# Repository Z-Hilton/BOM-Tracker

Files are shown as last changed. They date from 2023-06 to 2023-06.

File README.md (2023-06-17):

# BOM-Tracker
A guide to how I built the ultimate DIY Book of Mormon Progress Tracker. It is designed to help with reading goals and make tracking your progress through the Book of Mormon just a bit more fun.

## Background
I wanted something that would essentially function like a glorified bookmark, keeping track of stats, times, progress, averages, etc. I thought about making an app for a smartphone, but decided that another app that I eventually forget about wouldn't be as exciting as a physical piece of hardware that can sit on my nightstand as a constant reminder that I only get to click its buttons if I have read :) (Also, I try to avoid being on my phone before going to bed). Thus the idea to use a microcontroller was born. I thought abut using a Teensy 3.2 since I already have one, but decided that for reproducability's sake I would use the much cheaper $4 Raspberry Pi Pico. 

## Functionality
* *Time tracking:* You can start, pause and stop a timer to track your time spent reading. The spent time will be displayed briefly on the OLED screen before returning to the normal UI, then after 7 times, it will calculate your weekly average and display that to the screen, allowing you to see if you met your goal. 
* *Chapter progress tracking:* You can increment and decrement which chapter you're on and update the display accordingly. Then it will do the math to show the total progress and display it on the OLED screen as a percentage or progress bar.
* *User interface:* It has a simple UI consisting of a few buttons for selecting chapters and start/pause/stopping the timer. The OLED display will provide feedback on the device's status and progress. An external LED shows the current timer status (started = on, paused = blinking, stopped = off). 

## Bill of Materials
Warning: *the following cost analysis assumes you have access to an FDM and Resin 3D printer. These are based on rates I found locally at BYU* 

I spent about $25 on this project, and ended up with lots of extra parts. I also had to iterte a few times on my designs for the housing and the keycaps before they worked well. In theory you could build this in under $17.30:
Item # | Description | Quantity | Cost Per Item | Cost
---|---|---|---|---
1 | [Raspberry Pi Pico](https://www.raspberrypi.com/products/raspberry-pi-pico/) | 1 | $4.00 | $4.00
2 | [Micro USB Cable](https://www.amazon.com/CableWholesale-10-Feet-Micro-Cable-10U2-03110BK/dp/B002I8MUJG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) | 1 | $2.00 | $2.00
3 | [PLA filament](https://www.amazon.com/OVERTURE-Filament-Consumables-Dimensional-Accuracy/dp/B07PGY2JP1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) | 50 grams | $20/kg | $1.00
4 | LED (any color) | 1 | $0.10 | $0.10
5 | [Keyboard Switches](https://www.amazon.com/Switches-Replaceable-Equivalent-Keyswitch-Mechanical/dp/B09WHDJJBT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) | 3 | $10/10pc | $3.00
6 | Resin Keycaps | 3 | $0.25/ml | $1.20
7 | [SSH1106 1.3" OLED](https://www.amazon.com/Teyleten-Robot-Display-Raspberry-Microcontroller/dp/B08J1D212N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) | 1 | $12/2pc | $6.00

## Build/Pictures
[Here is a link](https://www.thingiverse.com/thing:4816077) to the model I started with and modified to suit the needs of my 3 buttons and OLED screen. They are relatively simple edits and can be done very quickly in Fusion 360. I did not modify the bottom half, and the changes I made to the top half are reflected in the .stp file I exported and included above. 

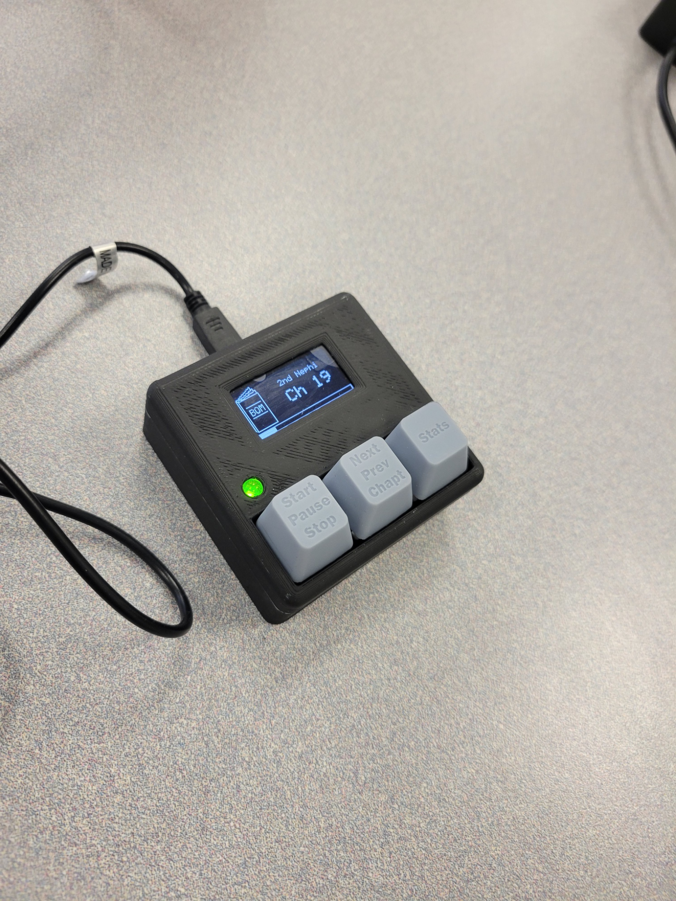
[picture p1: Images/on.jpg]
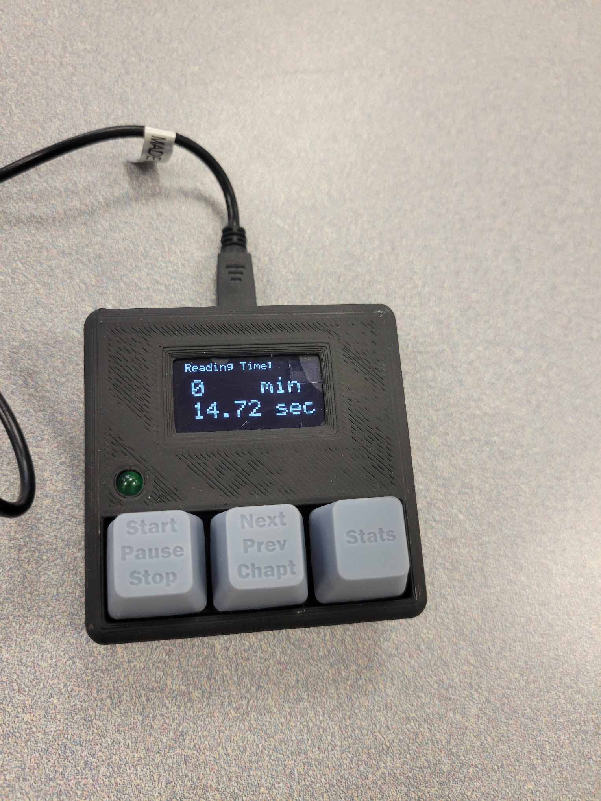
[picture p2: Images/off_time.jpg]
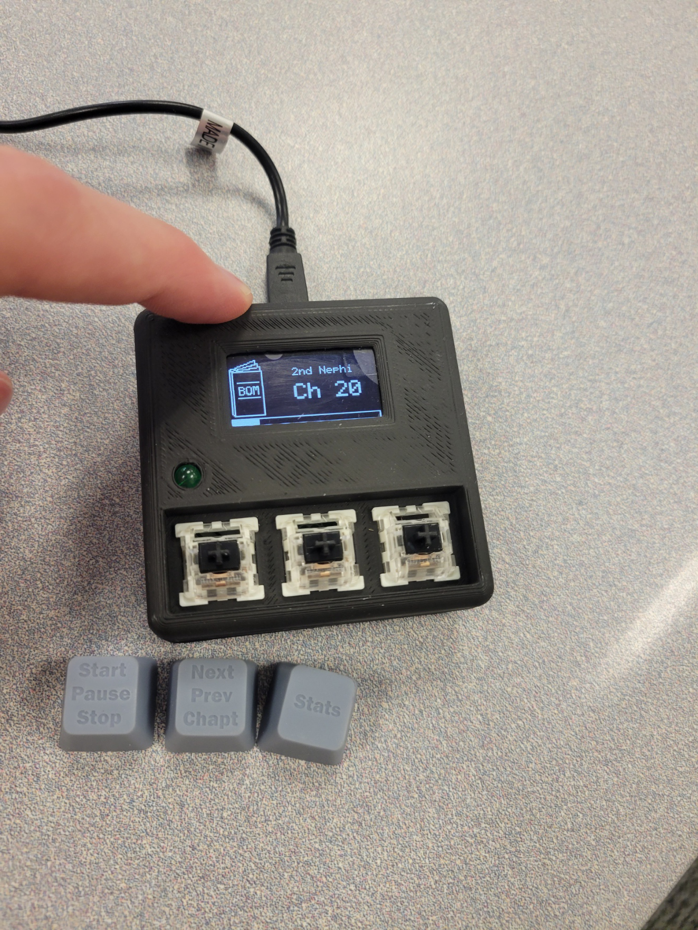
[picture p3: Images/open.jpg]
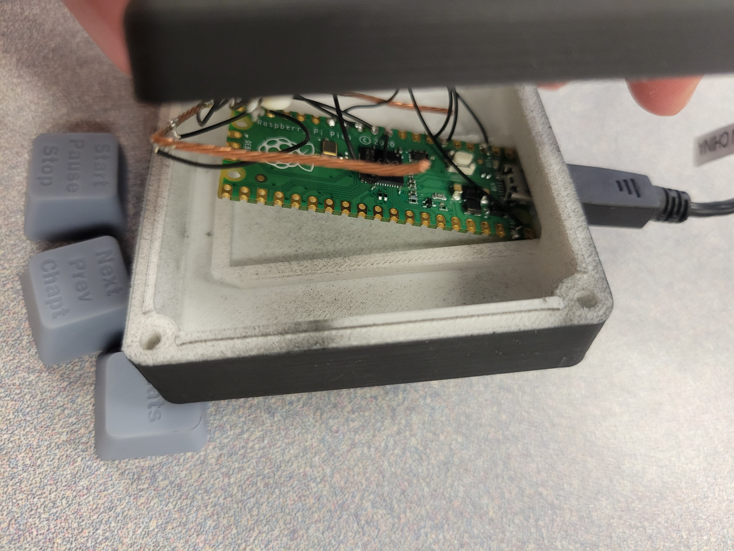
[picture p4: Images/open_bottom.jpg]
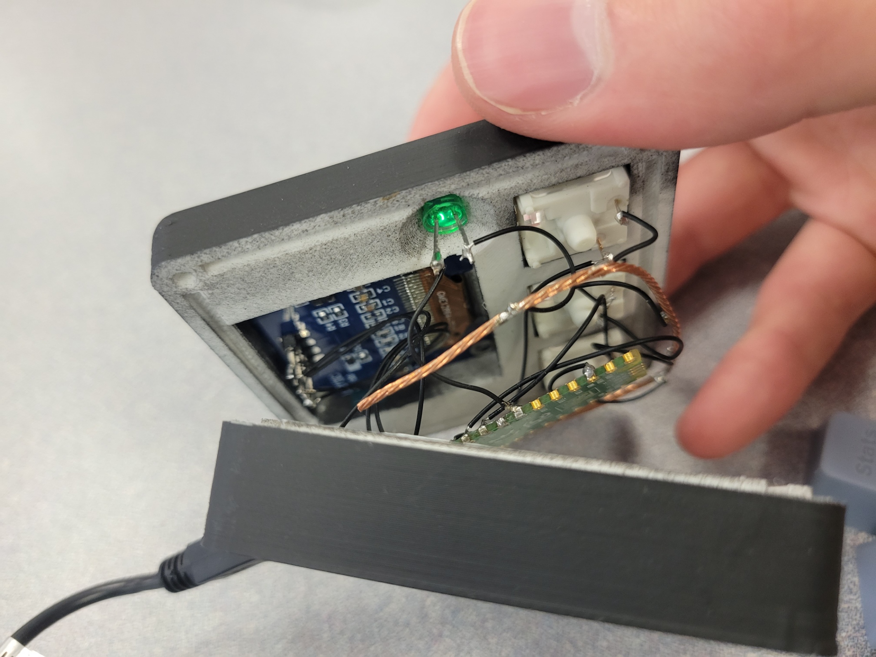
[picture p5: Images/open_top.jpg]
    

## Video


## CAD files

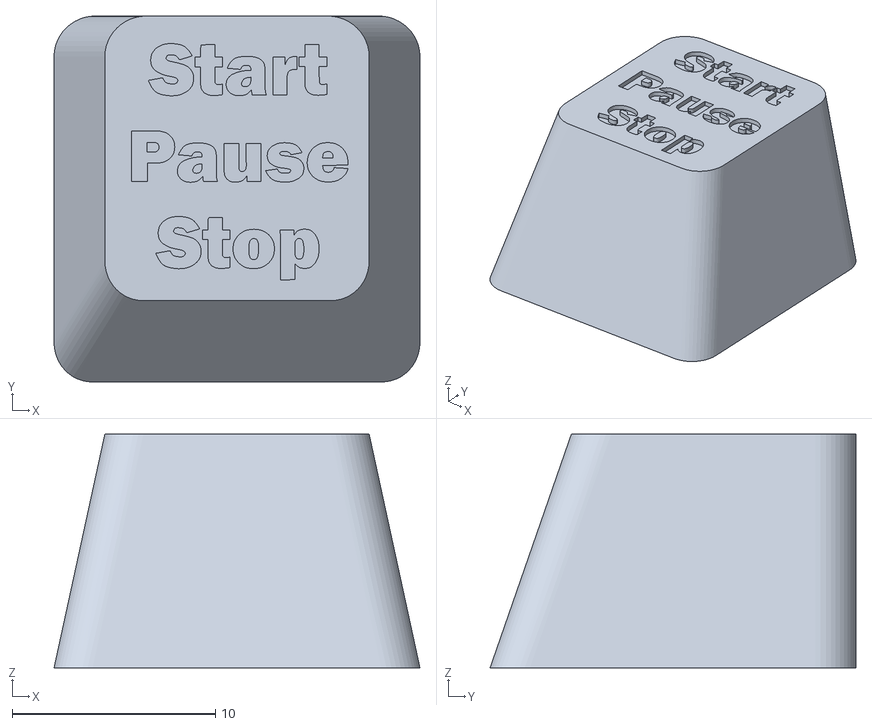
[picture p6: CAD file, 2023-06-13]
cherry_mx_key_cap_edited.stl
18.0 x 18.0 x 11.5

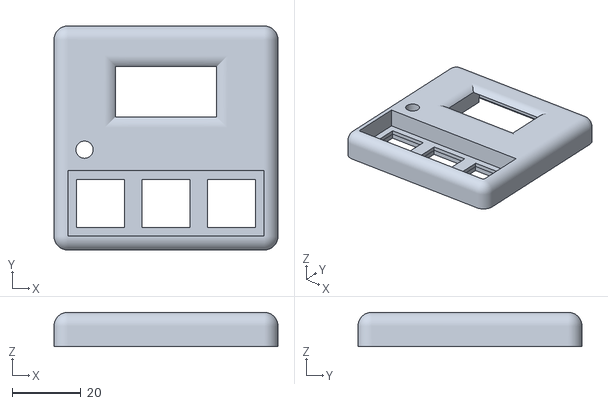
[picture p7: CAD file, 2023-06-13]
case_top.stl
65.2 x 65.1 x 10.0

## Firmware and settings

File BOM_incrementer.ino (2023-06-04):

#define SPLASH_SCREEN_FRAME_COUNT 1
#define SPLASH_SCREEN_WIDTH 32
#define SPLASH_SCREEN_HEIGHT 63

const unsigned char splashScreen [] PROGMEM = {
0x00, 0x80, 0x80, 0x80, 0x80, 0xC0, 0x40, 0xA0, 0xA0, 0xA0, 0x90, 0x90, 0x50, 0x48, 0x48, 0x28,
0x24, 0xA4, 0xA2, 0xB2, 0x92, 0x91, 0x9F, 0x88, 0x78, 0x40, 0xC0, 0x00, 0x00, 0x00, 0x00, 0x00,
0xFF, 0x03, 0xFE, 0x06, 0x05, 0x05, 0x07, 0x07, 0x06, 0x06, 0x06, 0x06, 0x05, 0x05, 0x05, 0x05,
0x05, 0x05, 0x04, 0x04, 0x04, 0x04, 0x04, 0x04, 0x04, 0x04, 0x07, 0xFC, 0x00, 0x00, 0x00, 0x00,
0xFF, 0x00, 0xFF, 0x00, 0x00, 0x00, 0x10, 0x10, 0x10, 0x10, 0x10, 0x10, 0x10, 0x10, 0x10, 0x10,
0x10, 0x10, 0x10, 0x10, 0x10, 0x10, 0x10, 0x10, 0x10, 0x00, 0x00, 0xFF, 0x00, 0x00, 0x00, 0x00,
0xFF, 0x00, 0xFF, 0x00, 0x00, 0x00, 0x00, 0xFF, 0x89, 0x89, 0x89, 0x76, 0x00, 0x7E, 0xC1, 0x81,
0xC1, 0x7E, 0x00, 0xFF, 0x03, 0x0E, 0x03, 0xFF, 0x00, 0x00, 0x00, 0xFF, 0x00, 0x00, 0x00, 0x00,
0xFF, 0x00, 0xFF, 0x00, 0x00, 0x00, 0x04, 0x04, 0x04, 0x04, 0x04, 0x04, 0x04, 0x04, 0x04, 0x04,
0x04, 0x04, 0x04, 0x04, 0x04, 0x04, 0x04, 0x04, 0x04, 0x00, 0x00, 0xFF, 0x00, 0x00, 0x00, 0x00,
0xFF, 0x00, 0xFF, 0x00, 0x00, 0x00, 0x00, 0x00, 0x00, 0x00, 0x00, 0x00, 0x00, 0x00, 0x00, 0x00,
0x00, 0x00, 0x00, 0x00, 0x00, 0x00, 0x00, 0x00, 0x00, 0x00, 0x00, 0xFF, 0x00, 0x00, 0x00, 0x00,
0x01, 0x02, 0x07, 0x04, 0x04, 0x04, 0x04, 0x04, 0x04, 0x04, 0x04, 0x04, 0x04, 0x04, 0x04, 0x04,
0x04, 0x04, 0x04, 0x04, 0x04, 0x04, 0x04, 0x04, 0x04, 0x04, 0x04, 0x07, 0x00, 0x00, 0x00, 0x00,
0x00, 0x00, 0x00, 0x00, 0x00, 0x00, 0x00, 0x00, 0x00, 0x00, 0x00, 0x00, 0x00, 0x00, 0x00, 0x00,
0x00, 0x00, 0x00, 0x00, 0x00, 0x00, 0x00, 0x00, 0x00, 0x00, 0x00, 0x00, 
};




#include <Bounce2.h>
#include <string.h>
#include <GyverOLED.h>

#define TOTAL_CHAPTERS 239.0
#define SCREEN_WIDTH 128
#define SCREEN_HEIGHT 64
#define HOLD_TIME 1000
#define SHOW_PROGRESS 0
#define SHOW_TIMES 1
#define SHOW_STATS 2
//Initialize LCD by creating an OLED  object
GyverOLED<SSH1106_128x64> oled;


//define buttons and LED
const int incrementDecrementButtonPin = 8;
const int startPauseStopButtonPin = 7; // will be startPauseStopPin
const int statButtonPin = 9; // will be stat pin
const int ledPin = 10;
Bounce incrementDecrementButton = Bounce();
Bounce startPauseStopButton = Bounce();
Bounce statButton = Bounce();

//Book of Mormon constants and variables
const int numBooks = 15; // number of Books in th Book of Mormon
const int numChapters[] = {0, 22, 33, 7, 1, 1, 1, 1, 29, 63, 16, 30, 1, 9, 15, 10};
int currentBook = 1;    // the current book (starts with 1st Nephi)
int currentChapter = 1; // the current chapter (it starts with 1)
double portion = 0; // the percentage of the way through the Book of Mormon you are
double avg = 0;
// Define inc/dec timer variables
int holdCnt = 0;
bool incDecPressed = false;

//Define Timer State variables
bool timerRunning = false;
bool timerPaused = false;
bool flashLedFlag = false;  // Flag to trigger flashing mechanism
bool on = true;             // Flag to remember the current state of the LED
double startTime = 0.0;
double pauseTime = 0.0;
double elapsedTime = 0.0;
double weeklyTimes[] = {0.0, 0.0, 0.0, 0.0, 0.0, 0.0, 0.0};
int timesIndex = 0;
int flashCnt = 0;
int mode = 0;

void setup() {
  // Set the pin modes
  pinMode(incrementDecrementButtonPin, INPUT_PULLUP);
  pinMode(startPauseStopButtonPin, INPUT_PULLUP);
  pinMode(statButtonPin, INPUT_PULLUP);
  pinMode(ledPin, OUTPUT);
  // start the serial communication
  Serial.begin(9600); 
  // attach the Bounce objects to the button pins and set debounce intervals
  incrementDecrementButton.attach(incrementDecrementButtonPin); 
  incrementDecrementButton.interval(20); 
  startPauseStopButton.attach(startPauseStopButtonPin);
  startPauseStopButton.interval(20);
  statButton.attach(statButtonPin);
  statButton.interval(20);
  //Initialize the OLED display
  oled.init();
  oled.clear();
  oled.update();
  printUI();
  printChapter();
  // oled.setCursorXY(28,26);
  // oled.print("Hello World!");
  // oled.rect(0,0,127,63,OLED_STROKE);
  // oled.update();
}

void loop() {
  incrementDecrementButton.update(); // update the bounce object for the inc. button
  startPauseStopButton.update();// etc.
  statButton.update();

  if (incrementDecrementButton.read() == LOW && incrementDecrementButton.duration() >= HOLD_TIME) {
    if (currentChapter == 1) { // if we are at the first chapter of any given book,
      currentBook = ((currentBook - 2 + numBooks) % numBooks) + 1; //move to the previous book (this line was hard)
      currentChapter = numChapters[currentBook]; //start at the last chapter 
    } else {
      currentChapter--; //decrement the current chapter
    }
    printChapter();
  }
  else if (incrementDecrementButton.fell()) {// if the increment button was pressed
    if (currentChapter == numChapters[currentBook]) {// if we are on the last chapter of a given book,
      currentBook = (currentBook % numBooks) + 1; // move on to the next book
      currentChapter = 1; // start at the first chapter of the book
    } else {
      currentChapter++; // increment the current chapter
    }
    printChapter();
  }

  //state machine for the timer

  // Check if stop button is pressed
  if (startPauseStopButton.read() == LOW && startPauseStopButton.duration() >= HOLD_TIME && timerRunning) {
    // Stop timer
    timerRunning = false;
    timerPaused = false;
    flashLedFlag = false;
    digitalWrite(ledPin, LOW);
    Serial.print("Elapsed time: ");

    printTime(elapsedTime/1000.0,2,false,false);
    pushElapsedTime();
    //delay(3000);
    //printChapter();
    
    elapsedTime = 0.0;
  }
  // Check if the start/pause button is pressed
  else if (startPauseStopButton.fell()) {
    if (!timerRunning) {
      // Start the timer
      timerRunning = true;
      startTime = millis();
      digitalWrite(ledPin, HIGH);
    } else if (timerPaused) {
      // Resume the timer
      timerPaused = false;
      flashLedFlag = false;
      startTime += millis() - pauseTime;
      digitalWrite(ledPin, HIGH);
    } else {
      // Pause Timer
      timerPaused = true;
      pauseTime = millis();
      flashLedFlag = true;
    }
  }

  //Update the elapsed time if timer is running
  if (timerRunning && !timerPaused) {
    elapsedTime = millis() - startTime;
  }
  // Flash the LED
  if (flashLedFlag) {
    flashCnt++;
    if (flashCnt >= 10000) {
      if(on) {
        digitalWrite(ledPin, LOW);
        on = false;
        flashCnt = 0;
      } else {
        digitalWrite(ledPin, HIGH);
        on = true;
        flashCnt = 0;
      }
    }
  }

  if (statButton.fell()) {
    switch (mode) {
      case SHOW_PROGRESS:
        printStats(); // if we are in progress mode, pressing the stat button will show us stats
      break;
      case SHOW_TIMES:
        printChapter(); // if we are in showTimes mode, pressing the stat button will go to the chapter progress
      break;
      case SHOW_STATS:
        printChapter(); // if we are in showStats mode, pressing the stat button will go back to chapter progress 
      break;
    }
  }

  //delay(10); //small delay to prevent bouncing
}
void printChapter() {
  mode = SHOW_PROGRESS;
  Serial.print("Ch ");
  Serial.print(currentChapter);
  Serial.print(" of ");
  Serial.println(bookName(currentBook));

  //clean slate with my BOM UI
  oled.clear();
  printUI();

  // chapter to oled
  oled.setScale(1);
  //We gotta fit Words of Mormon in there so here is the exception case
  if(currentBook == 7) {
    oled.setCursorXY(37, 10);
    oled.println(bookName(currentBook));
  } else {
    oled.setCursorXY(55, 10);
    oled.println(bookName(currentBook));
  }
  oled.setCursorXY(55, 25);
  oled.setScale(2);
  oled.print("Ch ");
  oled.print(currentChapter);

  // progress bar
  double sum = 0.0;
  for (int i = 0; i < currentBook; i++) {
    sum += numChapters[i];
  }
  sum += currentChapter;
  portion = sum/TOTAL_CHAPTERS;
  int progress = portion * SCREEN_WIDTH;
  oled.rect(0,54,127,60,OLED_STROKE);
  oled.rect(0,55,progress,59,OLED_FILL);
  oled.update();
}

void printTime( double val, byte precision, bool weeklyFlag, bool statFlag){
  // prints val with number of decimal places determine by precision
  // precision is a number from 0 to 6 indicating the desired decimial places
  // example: printDouble( 3.1415, 2); // prints 3.14 (two decimal places)
  mode = SHOW_TIMES;
  int minutes = 0;
  while(val > 60.0) {
    minutes++;
    val -= 60;
  }
  Serial.print(minutes);
  Serial.print(" min ");
  Serial.print(int(val));  //prints the int part
  //print to the OLED
  oled.clear();
  oled.setScale(1);
  oled.setCursorXY(10, 0);
  if(weeklyFlag && !statFlag) oled.print("Weekly Average:");
  else if(weeklyFlag && statFlag) oled.print("Last Week's Avg:");
  else oled.print("Reading Time:");
  oled.setScale(2);
  oled.setCursorXY(15,15);
  oled.print(minutes);
  oled.print("    min");
  oled.setCursorXY(15, 35);
  oled.print(int(val));

  if( precision > 0) {
    Serial.print("."); // print the decimal point
    oled.print("."); 
    unsigned long frac;
    unsigned long mult = 1;
    byte padding = precision -1;
    while(precision--)
       mult *=10;
       
    if(val >= 0)
      frac = (val - int(val)) * mult;
    else
      frac = (int(val)- val ) * mult;
    unsigned long frac1 = frac;
    while( frac1 /= 10 )
      padding--;
    while(  padding--) {
      Serial.print("0");
      oled.print("0");

    }
    Serial.print(frac,DEC);
    Serial.print(" sec\n");
    oled.print(frac,DEC);
    oled.print(" sec");
  }
  oled.update();
}

void pushElapsedTime() {
  weeklyTimes[timesIndex] = elapsedTime / 1000.0;
  if (timesIndex == 6) {
    double sum = 0.0;
    for (int i = 0; i < 7; i++) {
      sum += weeklyTimes[i];
      weeklyTimes[i] = 0;
    }
    avg = sum/7.0;
    Serial.print("Your weekly avg: ");

    oled.setScale(1);
    oled.setCursorXY(10, 10);
    printTime(avg,2,true,false);
    timesIndex = 0;
  } else {
    timesIndex++;
  }
}

String bookName(int book) {
  switch (book) {
    case 1: return "1st Nephi";
    case 2: return "2nd Nephi";
    case 3: return "Jacob";
    case 4: return "Enos";
    case 5: return "Jarom";
    case 6: return "Omni";
    case 7: return "Words of Mormon";
    case 8: return "Mosiah";
    case 9: return "Alma";
    case 10: return "Helaman";
    case 11: return "3rd Nephi";
    case 12: return "4th Nephi";
    case 13: return "Mormon";
    case 14: return "Ether";
    case 15: return "Moroni";
    default: return "";
  }
}
void printUI() {
  //oled.home();
  oled.drawBitmap(1,1,splashScreen,SPLASH_SCREEN_WIDTH,SPLASH_SCREEN_HEIGHT,0,0);
  //oled.update();
}
void printStats() {
  mode = SHOW_STATS;
  oled.clear();
  oled.setScale(1);
  oled.setCursorXY(20, 10);
  oled.print("Progress: ");
  oled.print(portion*100);
  oled.print("%");
  oled.update();
  delay(2000);
  //printTime(avg,2,true,true);
}

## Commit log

2023-06-04 Updated README.md with a Bill of Materials
2023-06-13 Added .f3d and .stl files
    [case_top.stl, cherry_mx_key_cap_edited.stl]
